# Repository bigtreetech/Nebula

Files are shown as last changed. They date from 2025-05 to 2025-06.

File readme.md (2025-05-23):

# Introduction
The Nebula Smart Extruder is an ultra-lightweight (143g) direct drive smart extruder designed for highend CoreXY printers, Injection Molded from premium POM polymer. It features Integrated Filament sensor, Customizable Gcode button, RGB back-light, Hardened Large diameter gear and clear magnetic front cover.

# Wiki Link: https://bttwiki.com/Nebula.html

# Feature Highlights:
* Ultra-Lightweight: Enables faster, precise printing with minimal inertia.
* RGB Lighting: Programmable for visual status monitoring.
* Built-in Filament Sensor: Automatically triggers filament loading upon insertion.
* Transparent Magnetic Cover: Enables efficient maintenance checks and repairs.
* Customizable G-code Button: A programmable button for one-click filament unloading and other custom functions.
   * 6kg+ Reliable Extrusion Force: Precision planetary gears deliver over 6kg of extrusion power, with a hardened steel drive gear ensuring consistent and flawless extrusion for perfect prints.
   * Tension adjustment allowing you to master all filament
   * Planetary gear reduction


# Copyright

These files and the designs contained therein are copyright (c) 2025 BIQU.

These files and the designs contained therein are additionally licensed under **CC-BY-NC-ND-4.0**.

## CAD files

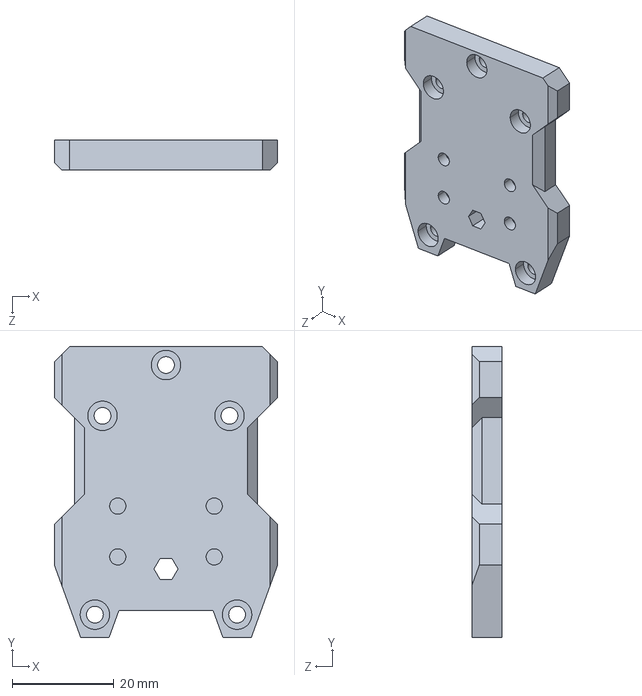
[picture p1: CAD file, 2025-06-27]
3D Model/EVA3/drive_Nebula_EVA3.STEP
44.0 x 57.3 x 6.00 mm

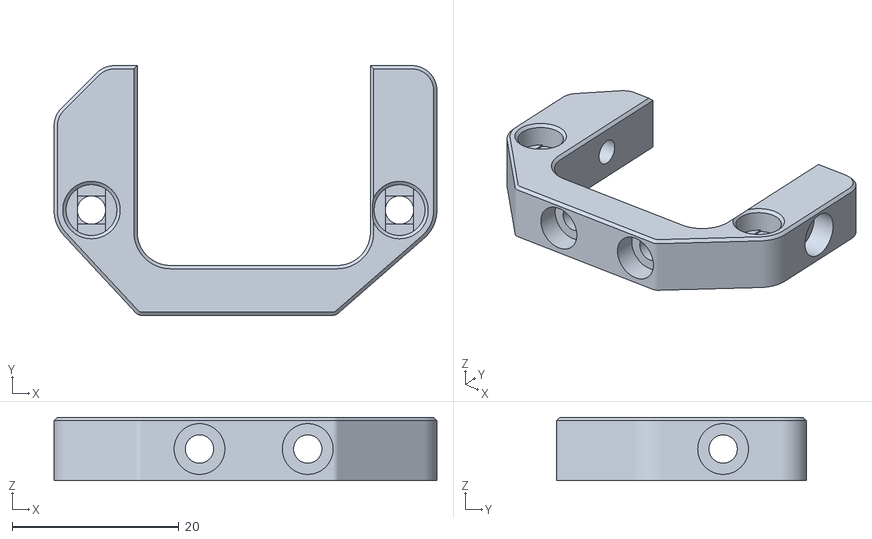
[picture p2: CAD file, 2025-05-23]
3D Model/Ratrig/Ratrig_Nebula_Adapter_Carriage_Part_by_Gizzzle.stl
46.0 x 30.0 x 7.60

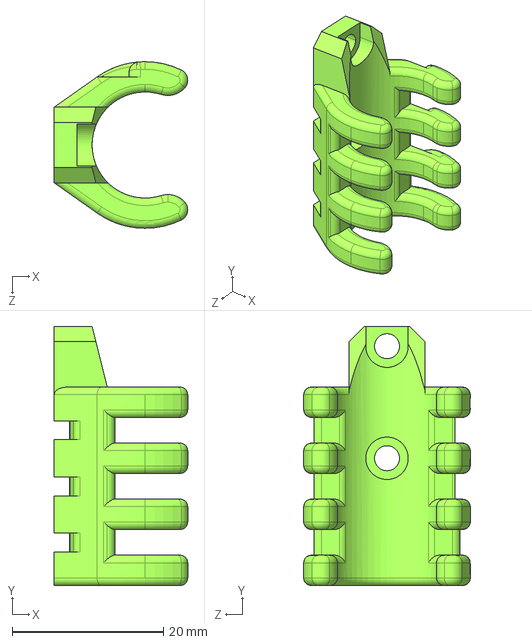
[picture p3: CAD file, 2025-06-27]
3D Model/EVA3/cable_guide_EVA3_nebula.STEP
17.6 x 34.2 x 22.0 mm

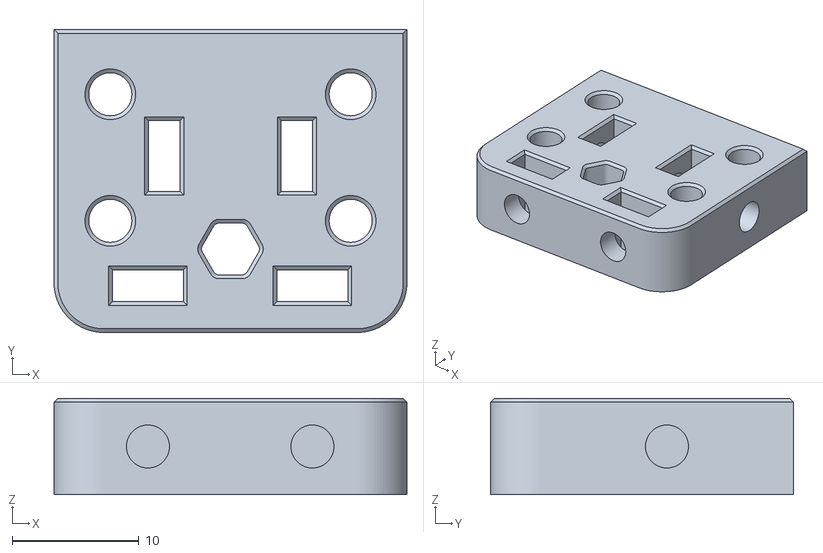
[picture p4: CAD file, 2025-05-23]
3D Model/Ratrig/Ratrig_Nebula_Adapter_Extruder_Part_by_Gizzzle.stl
27.9 x 24.0 x 7.60

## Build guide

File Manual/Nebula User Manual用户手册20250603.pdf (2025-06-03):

# Nebula 用户手册

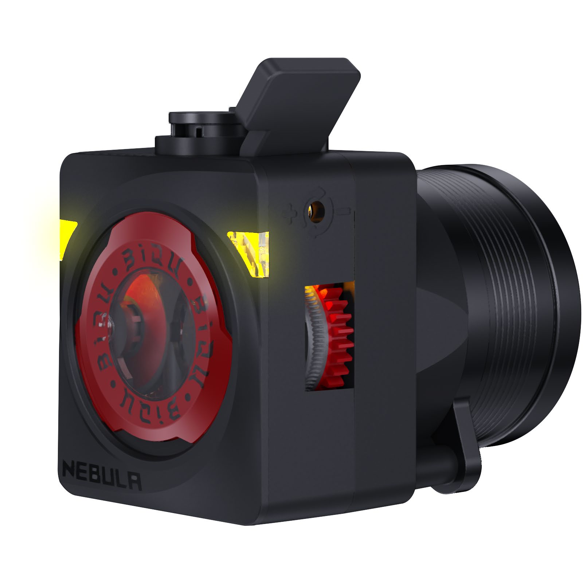
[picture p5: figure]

产品链接：https://biqu.equipment/products/biqu-nebula

Wiki：https://bttwiki.com/Nebula.html

GitHub：https://github.com/bigtreetech/Nebula

必趣创新科技（深圳）有限公司
Shenzhen BIQU Innovation Technology Co., Ltd.

2

## 产品简介

Nebula 是一款智能挤出机，专为提升性价比而设计，内置 RGB 背光灯，让打印头更具科技感。 产品具备强大的耗材挤出能力、内置耗材传感器，以及可自定义的 G-code 控制按钮，支持自动 进料和一键退料等多种实用功能。

## 产品特色

RGB 灯效：支持自定义色彩方案，直观显示打印机工作状态。

内置耗材检测模块：插入耗材，自动进料。

磁吸式透明其前盖： 透明可视设计，快速检修。

自定义 G-code 控制按钮：一键退料按钮，或自定义其他操作，提供灵活的控制选项。

6kg+ 稳定挤出力：精密行星齿轮减速系统和大直径硬化钢齿轮，提供超过 6kg 的挤出力，有效 减少打滑，适应多种耗材。

## 产品参数

挤出方式 | 双齿轮挤出
重量 | 143g
最大挤出力 | 6kg（取决于耗材）
Klipper Rotation Distance | 4.6
Rotation Distance（含齿轮传动比） | 51.75
推荐电机电流 | 800 mA
齿轮传动比 | 11.25 ：1
挤出轮周长 | 50.4mm
耗材直径及公差 | 1.75±0.05mm
电压 | 24V

## 产品尺寸

XYZ 尺寸：52.73 x 36.5 x 54.82mm

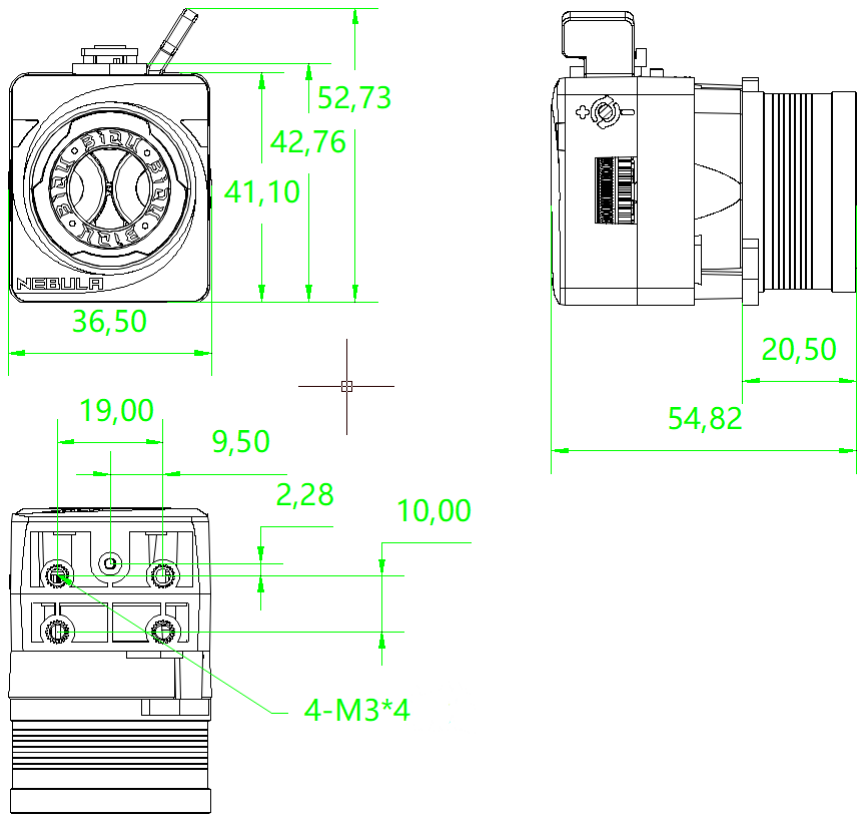
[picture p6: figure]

## 挤出齿轮的夹紧间距可调，适配不同类型的耗材

逆时针旋转调节螺钉（朝标记 “(–)” 的方向）可以减小间距、增加夹紧力，适合较硬的耗材 使用；顺时针旋转（朝标记 “(+)” 的方向）可以增大间距、降低夹紧力，更适合柔性耗材。

*注：当调节螺钉停止转动时，请勿用力，以免损坏挤出机结构。

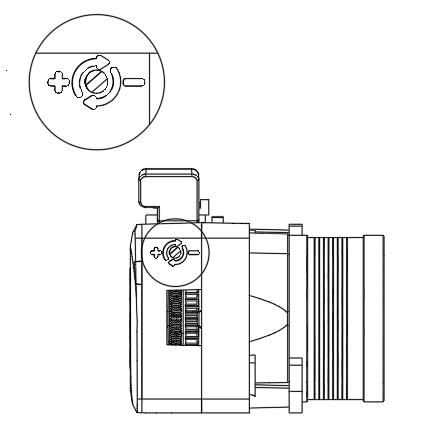
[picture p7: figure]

## 可编程按钮- Pin 脚介绍

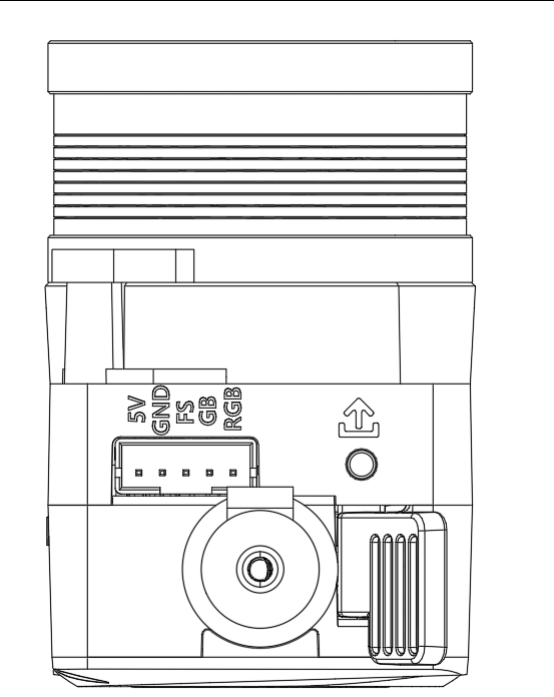
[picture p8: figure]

5V：电源输入；

GND: 接地；

FS：挤出机信号输出，无耗材高电平，有耗材低电平；

GB：按键信号输出：按键松开高电平，按键按下低电平；

RGB：RGB 灯信号输入，可以通过信号调节灯的颜色(关于 RGB

灯效的自定义设置，请参考由 julianschill 与 Paul

McGowan 开发的 klipper-led_effect 模块：

https://github.com/julianschill/klipper-led_effect/)

必趣创新科技（深圳）有限公司
Shenzhen BIQU Innovation Technology Co., Ltd.

5

## 电机规格

相数 | 2
步距角 | 1.8°
额定电压 | DC 2.4V
额定电流 | DC 1.0A
保持转矩 | ≥110mN·m
相电阻 | 2.4±10% ohm (20℃)
相电感 | 1.7±20% mH (1kHz)
转向（轴伸向看） | A-AB-B-CW
转动惯量 | 15 g·cm²
电机重量 | 0.1 kg
绝缘等级 | Class F

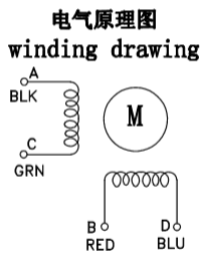
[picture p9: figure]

## 产品结构图

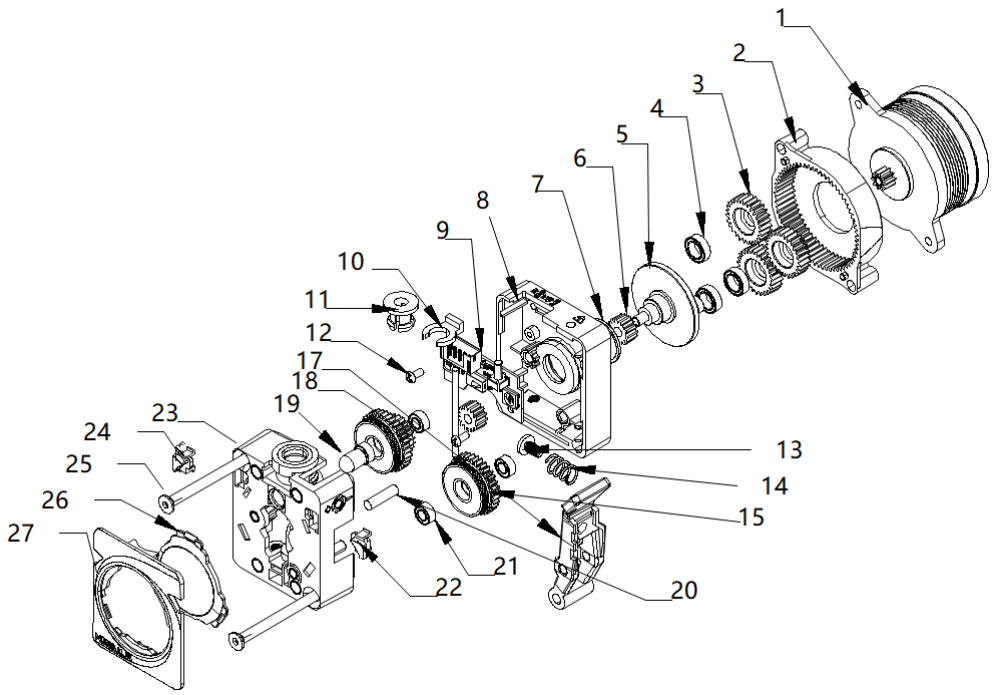
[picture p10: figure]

1. 电机 | 15. 惰轮
2. 齿圈盘 | 16. 3-5-6 PEEK 轴承
3. 行星小齿轮 | 17. 扳手
4. MR85ZZ 轴承 | 18. 挤出齿轮
5. 行星架 | 19. 耗材传感器模块
6. 14 齿齿轮 | 20. 滚花销钉 直径 3*11
7. MF128ZZ_轴承 | 21. 3-5-10 PEEK 轴承
8. 后壳 | 22. 右透镜
9. 配电板 | 23. 前壳
10. 卡扣 | 24. 左透镜
11. 卡爪 | 25. M3*25 沉头内六角螺丝

必趣创新科技（深圳）有限公司
Shenzhen BIQU Innovation Technology Co., Ltd.

7

12. M2x4 螺丝 | 26. 透盖
13. 调节螺钉 | 27. 磁吸盖框
14. 弹簧

## 购买链接:

https://biqu.equipment/products/biqu-nebula

如果您在使用产品过程中遇到任何问题，请提交支持工单：

https://biqu3d.com/pages/submit-a-ticket

网站导航:

BIQU 官网: http://biqu3d.com

BIGTREETECH 官网: http://bigtree-tech.com

在线商城: https://biqu.equipment

社区: https://community.biqu3d.com

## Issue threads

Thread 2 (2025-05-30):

ebb36 In addition to pd3, which other interface can control ws2812

windy0220, 2025-05-30:
pd3 is already occupied by my print head, nebula I tried to use PB5, PB7, it doesn't seem to work, even if it lights up, I can't control it

windy0220, 2025-06-01:
OK, I found it, I can use the probe interface

Closed 2025-06-01.

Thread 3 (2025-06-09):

Stealthburner nebula housing STL not manifold

Pneumanifest, 2025-06-09:
The housing part for the Nebula in the provided stealthburner STL is not manifold. If overlooked it will cause a failure starting at layer 11 or 12, as it causes a near full layer to be missing.

bigtreetech, 2025-06-10:
Thank you very much for your feedback. fixed file has been uploaded in c64e9644ec0943191c23a8a7162ce5bce07ce2cf.

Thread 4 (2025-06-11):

How do I use the Nebula and a Can bus board on a stealth burner

tez-uk, 2025-06-11:
I have a Nebula and a EBB SB2209 USB, the modified SB (stl) files do not provide enough clearance or attachments to use these together.

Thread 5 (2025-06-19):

Nebula EVA3 files aren't for the EVA3, they are for the RatRig Toolhead

Radther, 2025-06-19:
The Nebula is marketed to be drop in compatible with the EVA3 toolhead but the files provided are for the RatRig toolhead. The EVA3 is quite different and the holes don't easily line up.

These are the EVA 3 toolhead
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

This is the file provided on the github showing the RatRig toolhead
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

bigtreetech, 2025-06-27:
Fixed in https://github.com/bigtreetech/Nebula/commit/328bf4c2c882ca1cd91e262b03e81fa30fead5ee.
Thanks a lot.

Closed 2025-06-27.

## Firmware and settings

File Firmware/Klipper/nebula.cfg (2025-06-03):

[gcode_macro _NEBULA_VARIABLE]
# unload
variable_unload_purge_distance: 35   # (mm) purge a distance before unload to clean filament
variable_unload_purge_speed:    300  # (mm/min) purge speed
variable_unload_distance:       120  # (mm) unload distance
variable_unload_speed:          3000 # (mm/min) unload speed
# load
variable_load_distance:         40   # (mm) load distance
variable_load_speed:            1500 # (mm/min) load speed
variable_load_purge_distance:   70   # (mm) purge a distance after load
variable_load_purge_speed:      300  # (mm/min) purge speed
gcode:

[extruder]
rotation_distance: 51.75
gear_ratio: 11.25:1
max_extrude_only_distance: 200.0 # must be greater than the distance of the single segment above 

[respond]
default_type: echo

[gcode_macro NEBULA_UNLOAD_FILAMENT]
gcode:
  {% set nebula = printer['gcode_macro _NEBULA_VARIABLE'] %}
  {% set unload_purge_distance = nebula.unload_purge_distance %}
  {% set unload_purge_speed = nebula.unload_purge_speed %}
  {% set unload_distance = nebula.unload_distance %}
  {% set unload_speed = nebula.unload_speed %}

  SAVE_GCODE_STATE NAME=tmp_unload_state
  G91
  G92 E0
  M118 Nebula unload purging
  G1 E{unload_purge_distance} F{unload_purge_speed}
  M400
  M118 Nebula unloading
  G1 E-{unload_distance} F{unload_speed}
  M400
  RESTORE_GCODE_STATE NAME=tmp_unload_state

[gcode_macro NEBULA_LOAD_FILAMENT]
gcode:
  {% set nebula = printer['gcode_macro _NEBULA_VARIABLE'] %}
  {% set load_purge_distance = nebula.load_purge_distance %}
  {% set load_purge_speed = nebula.load_purge_speed %}
  {% set load_distance = nebula.load_distance %}
  {% set load_speed = nebula.load_speed %}

  SAVE_GCODE_STATE NAME=tmp_unload_state
  G91
  G92 E0
  M118 Nebula loading
  G1 E{load_distance} F{load_speed}
  M400
  M118 Nebula load purging
  G1 E{load_purge_distance} F{load_purge_speed}
  M400
  RESTORE_GCODE_STATE NAME=tmp_unload_state

[neopixel nebula_neopixel]
pin: EBBCan:PD3 # RGB pin（marked as RGB on extruder）, Modify this to match your mainboard！
chain_count: 2
color_order: GRB
initial_RED: 1.0
initial_GREEN: 1.0
initial_BLUE: 1.0

[gcode_button nebula_unload_button]
pin: ^!EBBCan:PB4 # Gcode Button pin（marked as GB on extruder）, Modify this to match your mainboard！
debounce_delay: 0.02
press_gcode:
release_gcode:
  {% if printer.print_stats.state != "printing" %}
    {% set fs = printer['gcode_button filament_sensor'] %}
    {% if fs.state == "RELEASED" %}
      NEBULA_UNLOAD_FILAMENT
    {% endif %}
  {% endif %}

[gcode_button filament_sensor]
pin: ^EBBCan:PB3 # Filament sensor pin（marked as FS on extruder）, Modify this to match your mainboard！
debounce_delay: 0.5
press_gcode:
  {% if printer.print_stats.state == "printing" %}
    PAUSE # [pause_resume] is required in printer.cfg
  {% endif %}
release_gcode:
  {% if printer.print_stats.state != "printing" %}
    NEBULA_LOAD_FILAMENT
  {% endif %}

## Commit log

2025-06-03 use gear_ration with rotation_distance
    [nebula.cfg]
2025-06-10 Fixed Non-Manifold stealthburner STL
2025-06-27 Updated EVA3 and Ratrig models
    [Ratrig_Nebula_Adapter_Carriage_Part_by_Gizzzle.stl, Ratrig_Nebula_Adapter_Extruder_Part_by_Gizzzle.stl, cable_guide_EVA3_nebula.STEP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]

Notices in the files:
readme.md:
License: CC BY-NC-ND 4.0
